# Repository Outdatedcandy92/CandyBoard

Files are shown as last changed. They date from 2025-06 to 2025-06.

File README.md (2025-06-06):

## Candy Board

Candy Board is a 75% compact keyboard powered by a Raspberry Pi Pico. It includes two knobs and a oled screen on board. Along with a 75% Keyboard you have a seperated dedicated numpad.



### Inspiration

I daily drive a keychron K2 and I really love that keyboard but I really wished it had better media control keys and seperate numpad for number crunching. To address these problems I added two rotary encodes on top and a mini oled screen on the main keyboard and also designed a seperate numpad

### BOM

**Prices are in CAD unless specified**
| **Component** | **Quantity Needed** | **Lot Price** | **Unit Price** |
| --- | --- | --- | --- |
| [Raspberry Pi Pico Clones](https://www.aliexpress.com/item/1005003371056277.html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) | 2 | $6.30 | $3.15 |
| **PCB** | - | $44.46 + $34.91 (Shipping) - $14.03 (Coupon) = **$65.34** | - |
| **Keyboard** | 1 | - | $31.84 |
| **Numpad** | 1 | - | $12.62 |
| **3D Case** [1 Kg Filament](https://www.amazon.ca/ELEGOO-Filament-Dimensional-Accuracy-Carboard/dp/B0CFV3WF7P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) | 5 | $25 | - |
| &nbsp;&nbsp;&nbsp;&nbsp;• Keyboard (Top, Bottom, Plate) | 3 | - | - |
| &nbsp;&nbsp;&nbsp;&nbsp;• Numpad (Case, Plate) | 2 | - | - |
| **Acrylic Cutout** | 2 | - | - |
| &nbsp;&nbsp;&nbsp;&nbsp;• Keyboard | 1 | - | - |
| &nbsp;&nbsp;&nbsp;&nbsp;• Numpad | 1 | - | - |
| [EC11 15mm Rotary Encoder](https://www.aliexpress.com/item/1005005721641382.html) | 2 | $5.34 | ~$1.00 |
| [MCP23017](https://www.aliexpress.com/item/1005005363863079.html) | 1 | $4.42 | $4.42 |
| [1N4148](https://www.aliexpress.com/item/1005002339916163.html) | 101 | $1.27 | $0.13 |
| [Cherry MX Red](https://www.aliexpress.com/item/1005006255961111.html) | 101 | $39.22 | $0.35 |
| [Keycaps](https://www.aliexpress.com/item/1005007393936770.html) | 1 set | $31.18 | $31.18 |
| [Stabilizer Set](https://www.aliexpress.com/item/1005001686319745.html) | 1 set | $8.67 | $8.67 |
| [SSD1306 0.91'' OLED](https://www.aliexpress.com/item/1005007302239124.html) | 1 | $4.42 | $4.42 |
| [SK6812 Mini-E](https://www.aliexpress.com/item/1005005193716172.html) | 8 | $3.18 | $0.16 |
| [Rubber Feet](https://www.aliexpress.com/item/1005006211282720.html) | 2 sets | $8.02 | $4.01 |
| [EVA Foam](https://www.aliexpress.com/item/1005002856054113.html) | 1 | $6.79 | $6.79 |
| **Sub Total** | - | **~$210** | - |
| **Taxes (13%)** | - | **~$27** | - |
| **Grand Total** | - | **~$237** = $174 USD | - |

### CAD Model:

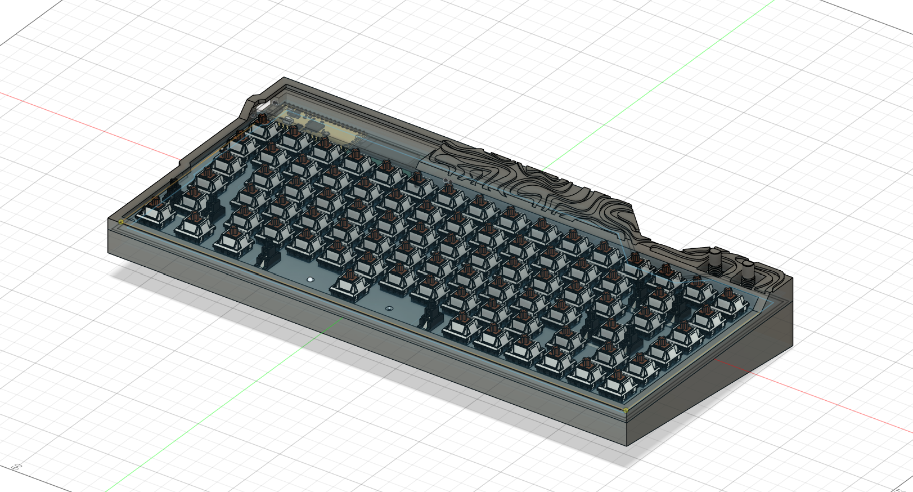
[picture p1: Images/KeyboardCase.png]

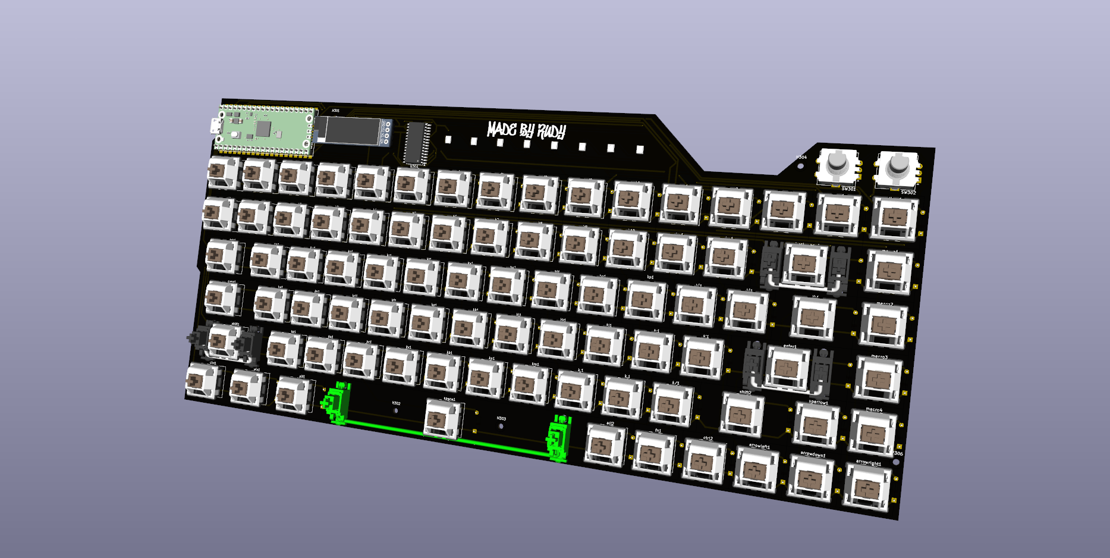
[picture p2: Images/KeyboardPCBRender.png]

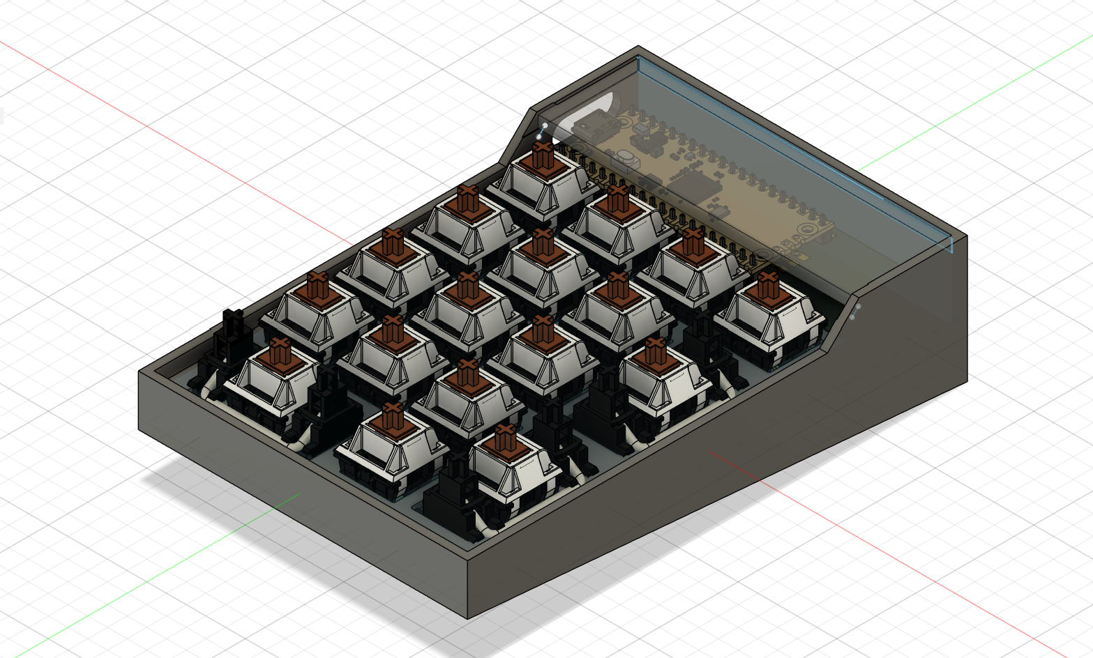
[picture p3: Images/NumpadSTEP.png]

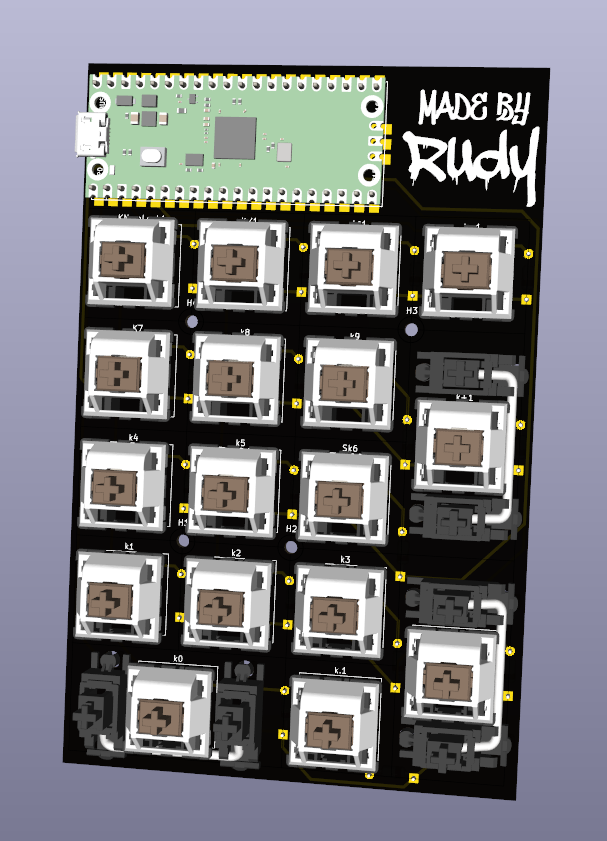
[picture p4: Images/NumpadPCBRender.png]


### PCB & Schematic
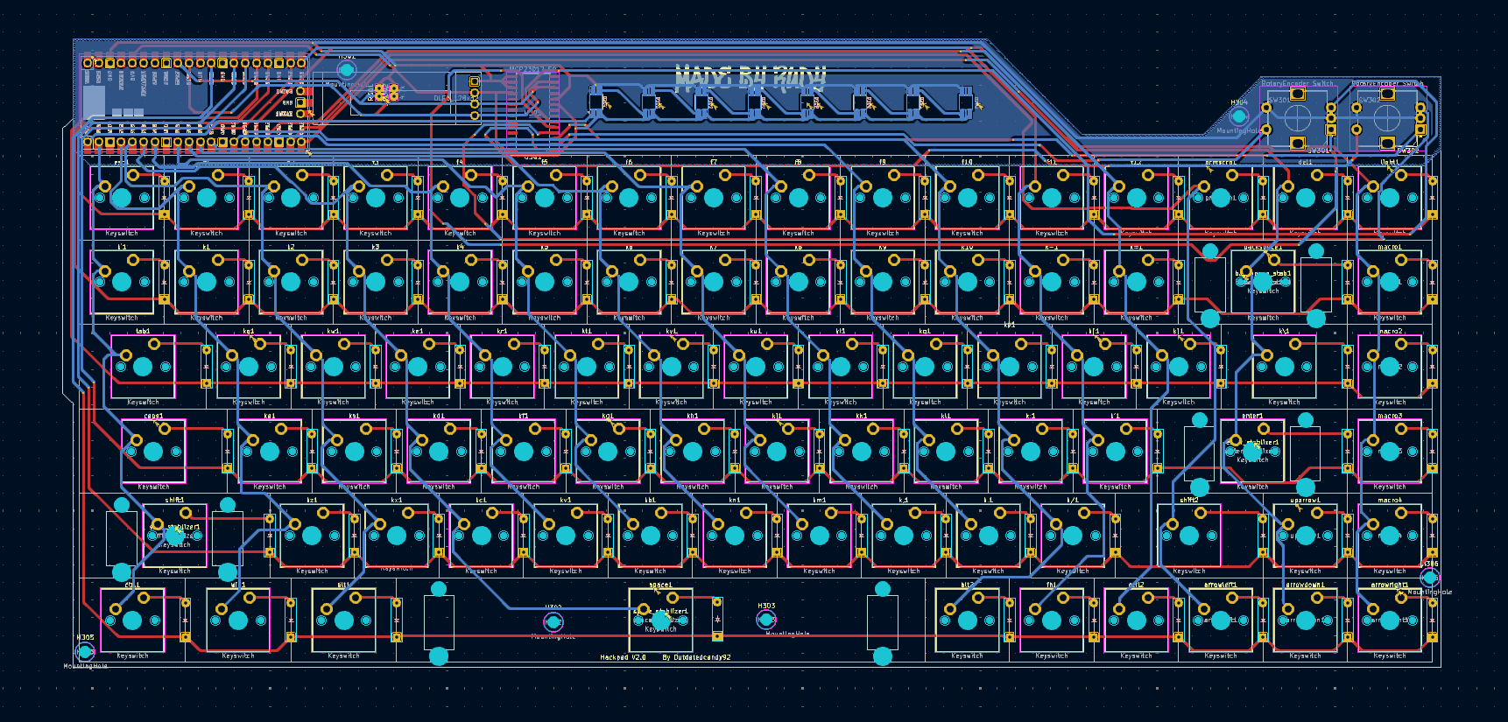
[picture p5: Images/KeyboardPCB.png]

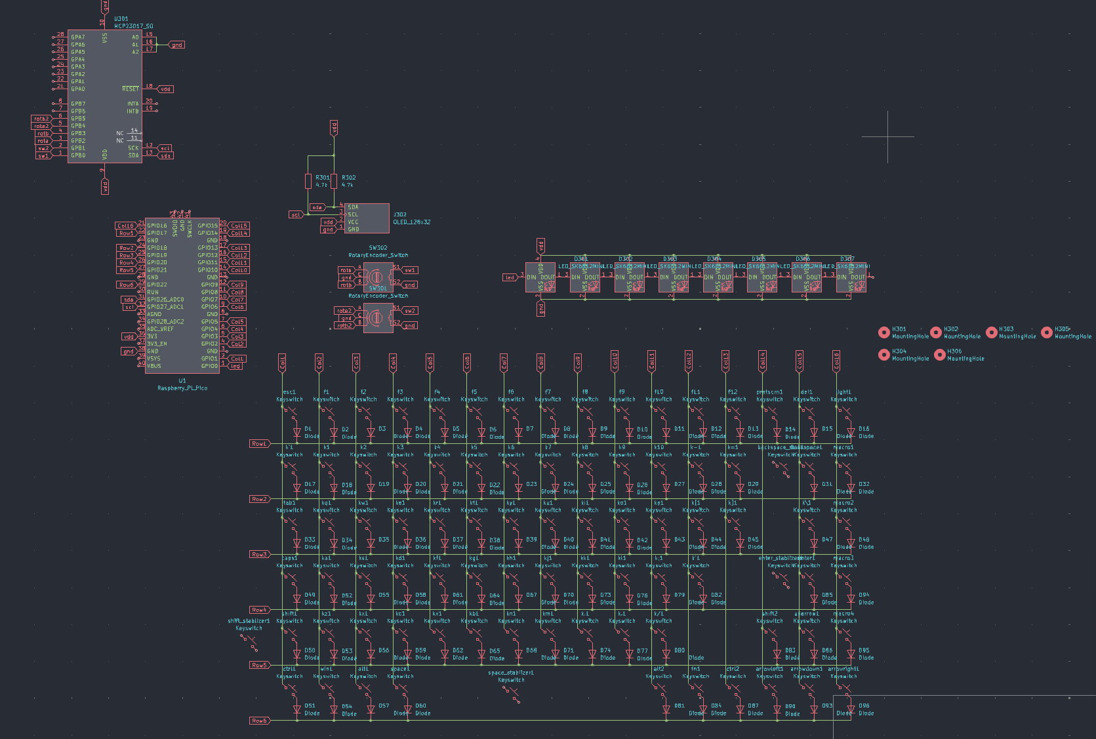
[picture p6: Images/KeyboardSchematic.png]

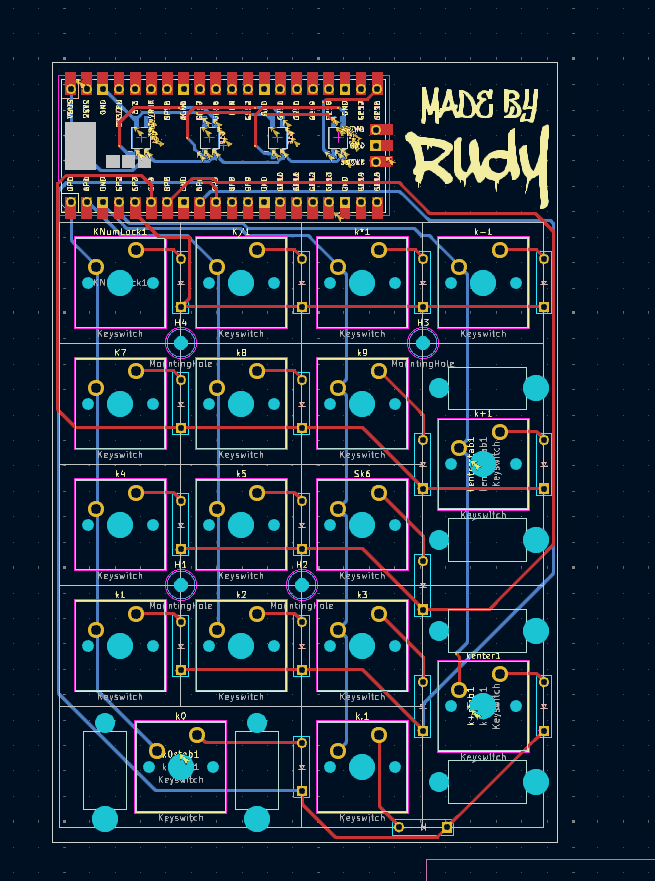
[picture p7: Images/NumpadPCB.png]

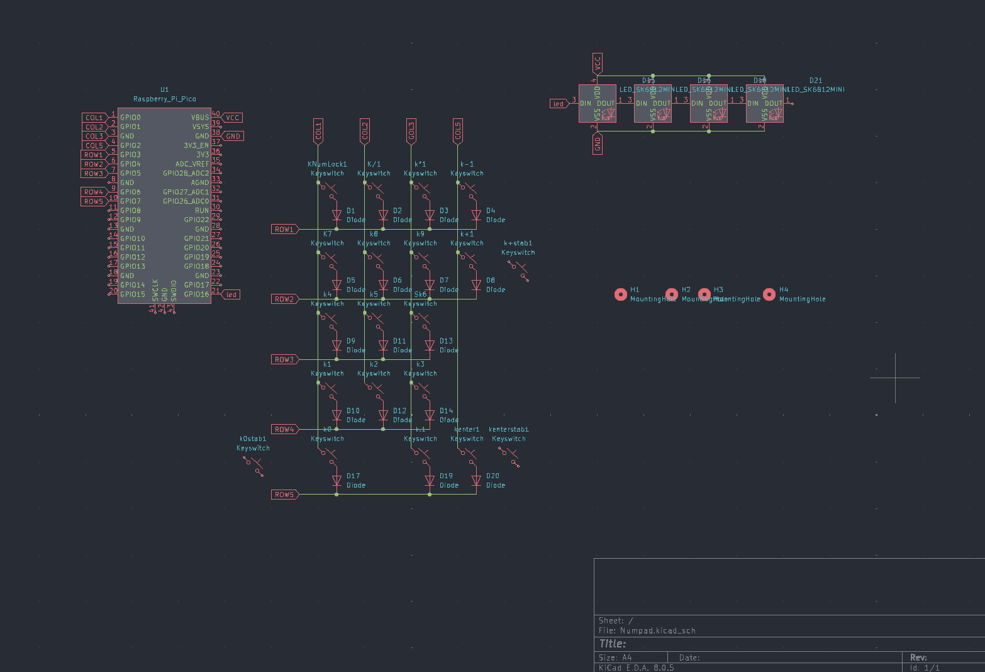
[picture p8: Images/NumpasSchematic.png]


### Firmware

Firmware was written using kmk. (no idea if it work rn tho)

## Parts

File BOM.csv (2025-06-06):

Item | Quantity Needed | Lot Price | Unit Price
Raspberry Pi Pico Clones | 2 | $6.30 | $3.15
PCB | - | $44.46 + $34.91 (Shipping) - $14.03 (Coupon) = $65.34 | -
Keyboard | 1 | - | $31.84
Numpad | 1 | - | $12.62
3D Case (1 Kg Filament) | 5 | $25 | -
• Keyboard (Top | Bottom | Plate) | 3 | - | -
• Numpad (Case | Plate) | 2 | - | -
Acrylic Cutout | 2 | - | -
• Keyboard | 1 | - | -
• Numpad | 1 | - | -
EC11 15mm Rotary Encoder | 2 | $5.34 | ~$1.00
MCP23017 | 1 | $4.42 | $4.42
1N4148 | 101 | $1.27 | $0.13
Cherry MX Red | 101 | $39.22 | $0.35
Keycaps (1 set) | 1 | $31.18 | $31.18
Stabilizer Set (1 set) | 1 | $8.67 | $8.67
SSD1306 0.91'' OLED | 1 | $4.42 | $4.42
SK6812 Mini-E | 8 | $3.18 | $0.16
Rubber Feet (2 sets) | 2 | $8.02 | $4.01
EVA Foam | 1 | $6.79 | $6.79
Sub Total | - | $210 | -
Taxes (13%) | - | $27 | -
Grand Total | - | $237 CAD ≈ $174 USD | -

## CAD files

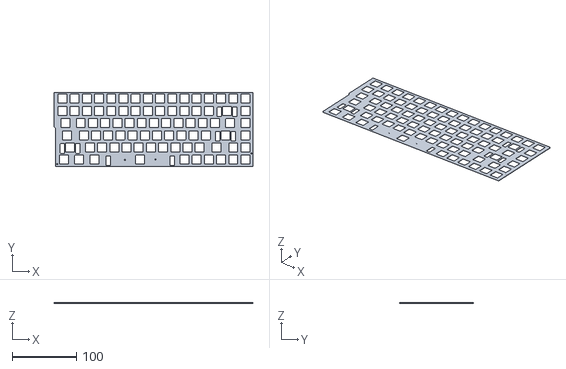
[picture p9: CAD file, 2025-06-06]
Production/Keyboard/KeyboardPlate.stl
310.8 x 115.3 x 1.50

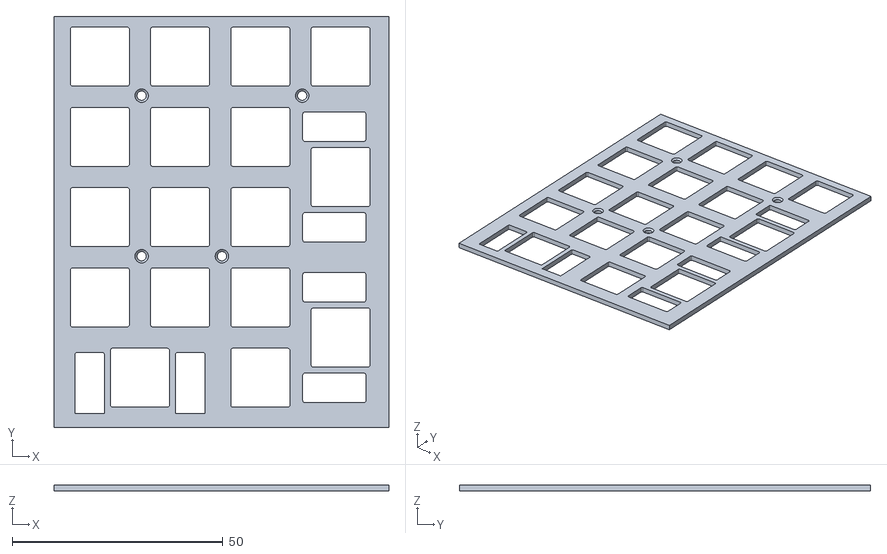
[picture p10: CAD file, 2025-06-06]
Production/Numpad/NumpadPlate.stl
79.5 x 97.6 x 1.50

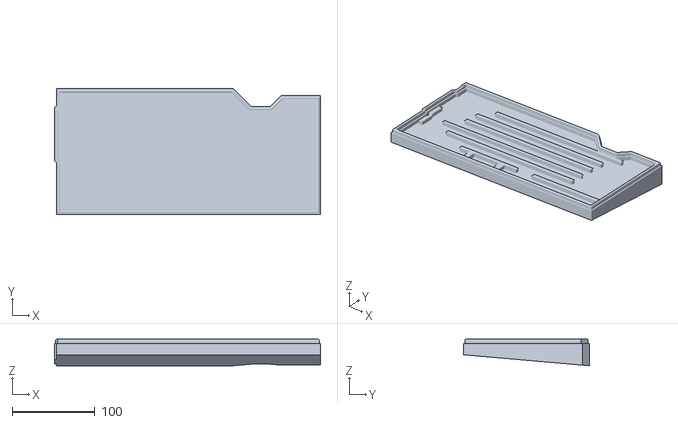
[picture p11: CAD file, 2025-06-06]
Production/Keyboard/KeyboardBottomCase.stl
320.8 x 151.7 x 32.0

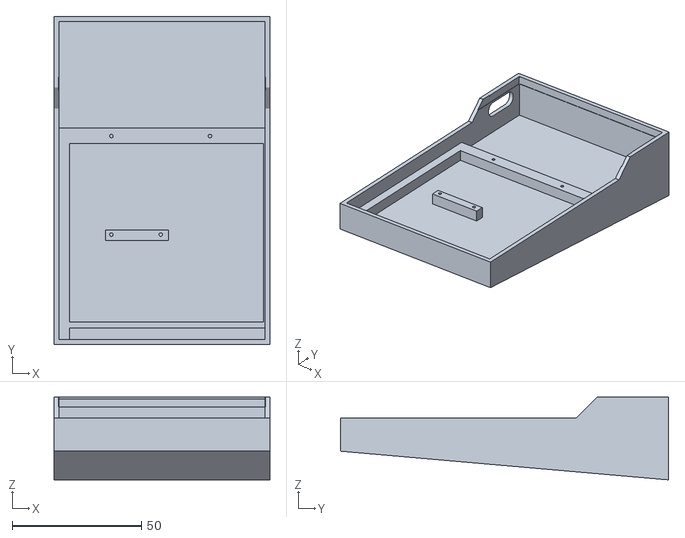
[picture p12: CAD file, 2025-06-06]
Production/Numpad/NumpadCase.stl
83.5 x 126.8 x 32.0

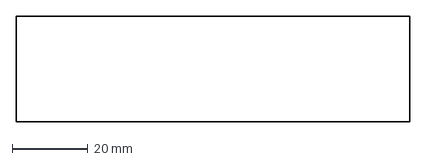
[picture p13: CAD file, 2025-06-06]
Production/Keyboard/KeyboardAcrylic.dxf
104.0 x 28.0 mm

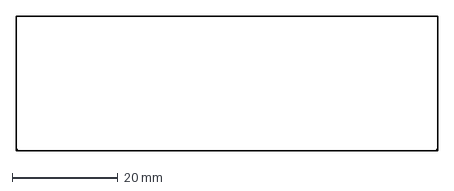
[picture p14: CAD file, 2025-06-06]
Production/Numpad/NumpadAcryllic.dxf
79.9 x 25.4 mm

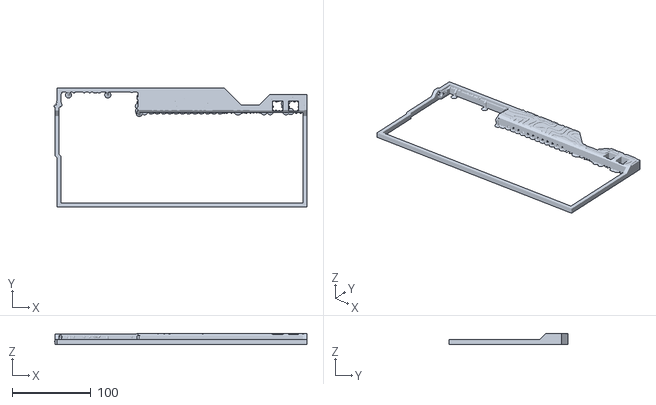
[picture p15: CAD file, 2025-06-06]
Production/Keyboard/KeyboardTopCaseWsupport.stl
322.3 x 151.7 x 14.6

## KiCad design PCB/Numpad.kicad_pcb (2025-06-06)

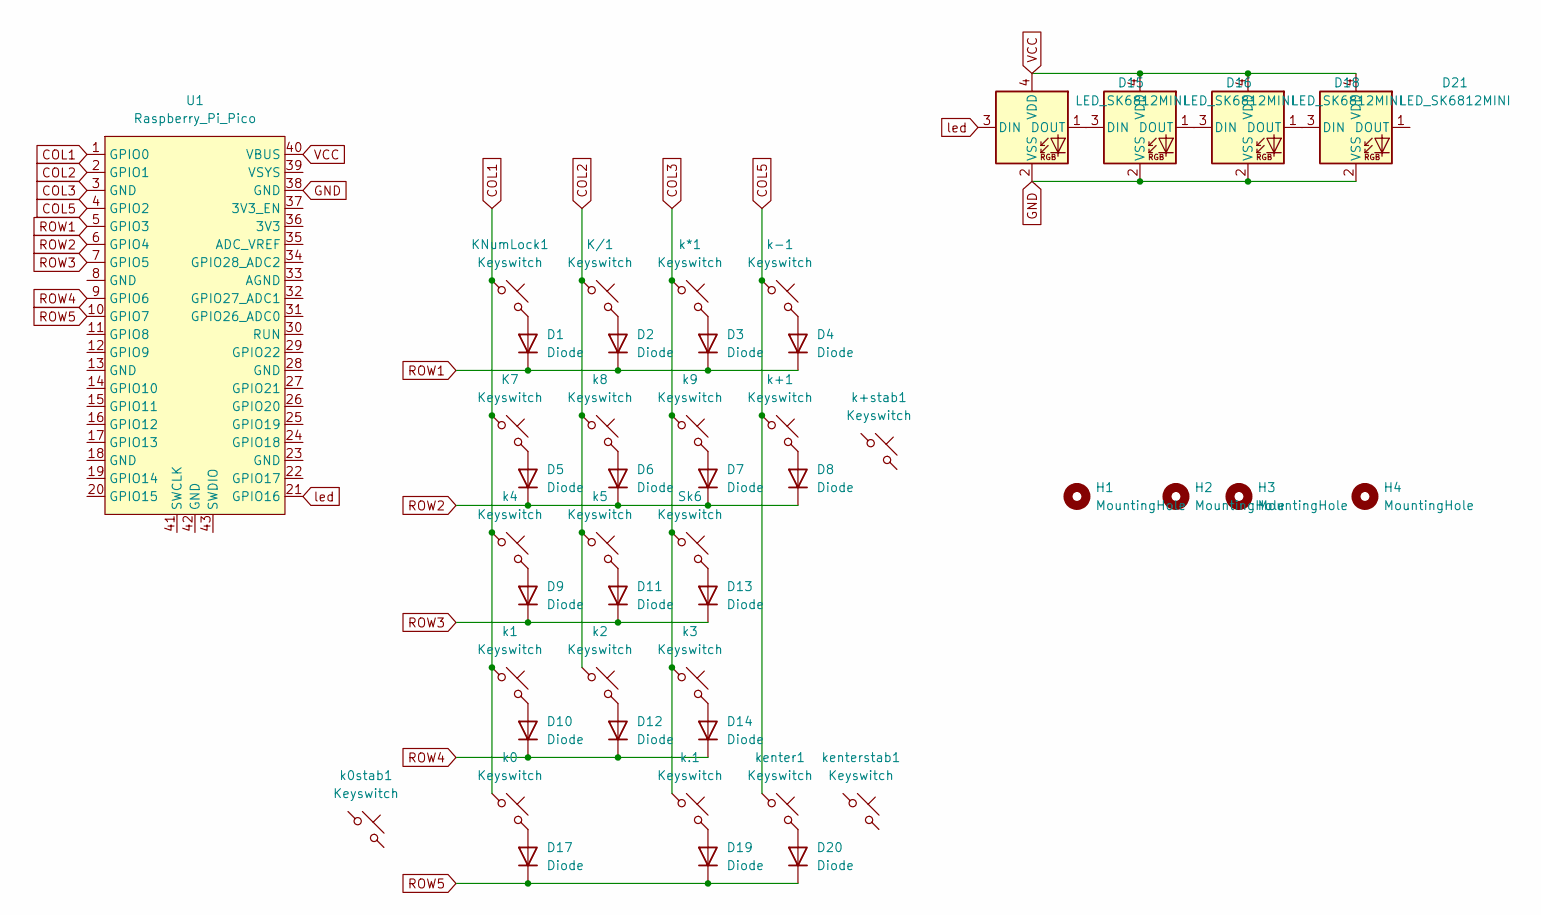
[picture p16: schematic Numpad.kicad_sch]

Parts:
D1, D2, D3, D4, D5, D6, D7, D8, D9, D10, D11, D12, D13, D14, D17, D19, D20: Diode; Diode_DO-35
D15, D16, D18, D21: LED_SK6812MINI
H1, H2, H3, H4: MountingHole; MountingHole_2.2mm_M2
K7: Keyswitch; MX_PCB_1.00u
K/1: Keyswitch; MX_PCB_1.00u
KNumLock1: Keyswitch; MX_PCB_1.00u
Sk6: Keyswitch; MX_PCB_1.00u
U1: Raspberry_Pi_Pico
k0: Keyswitch; MX_PCB_2.00u
k0stab1: Keyswitch; Stabilizer_MX_2.00u
k1, k2, k3, k4, k5, k8, k9, k.1: Keyswitch; MX_PCB_1.00u
k*1: Keyswitch; MX_PCB_1.00u
k+1: Keyswitch; MX_PCB_2.00u_90deg
k+stab1: Keyswitch; Stabilizer_MX_2.00u
k-1: Keyswitch; MX_PCB_1.00u
kenter1: Keyswitch; MX_PCB_2.00u_90deg
kenterstab1: Keyswitch; Stabilizer_MX_2.00u

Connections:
COL1: K7.1, KNumLock1.1, U1.1 (GPIO0), k0.1, k1.1, k4.1
COL2: K/1.1, U1.2 (GPIO1), k2.1, k5.1, k8.1
COL3: Sk6.1, U1.3 (GND), k3.1, k9.1, k*1.1, k.1.1
COL5: U1.4 (GPIO2), k+1.1, k-1.1, kenter1.1
GND: D15.2 (VSS), D16.2 (VSS), D18.2 (VSS), D21.2 (VSS), U1.38 (GND)
unnamed: D1.2 (A), KNumLock1.2
unnamed: D2.2 (A), K/1.2
unnamed: D3.2 (A), k*1.2
unnamed: D4.2 (A), k-1.2
unnamed: D5.2 (A), K7.2
unnamed: D6.2 (A), k8.2
unnamed: D7.2 (A), k9.2
unnamed: D8.2 (A), k+1.2
unnamed: D9.2 (A), k4.2
unnamed: D10.2 (A), k1.2
unnamed: D11.2 (A), k5.2
unnamed: D12.2 (A), k2.2
unnamed: D13.2 (A), Sk6.2
unnamed: D14.2 (A), k3.2
unnamed: D15.1 (DOUT), D16.3 (DIN)
unnamed: D16.1 (DOUT), D18.3 (DIN)
unnamed: D17.2 (A), k0.2
unnamed: D18.1 (DOUT), D21.3 (DIN)
unnamed: D19.2 (A), k.1.2
unnamed: D20.2 (A), kenter1.2
ROW1: D1.1 (K), D2.1 (K), D3.1 (K), D4.1 (K), U1.5 (GPIO3)
ROW2: D5.1 (K), D6.1 (K), D7.1 (K), D8.1 (K), U1.6 (GPIO4)
ROW3: D9.1 (K), D11.1 (K), D13.1 (K), U1.7 (GPIO5)
ROW4: D10.1 (K), D12.1 (K), D14.1 (K), U1.9 (GPIO6)
ROW5: D17.1 (K), D19.1 (K), D20.1 (K), U1.10 (GPIO7)
VCC: D15.4 (VDD), D16.4 (VDD), D18.4 (VDD), D21.4 (VDD), U1.40 (VBUS)
led: D15.3 (DIN), U1.21 (GPIO16)

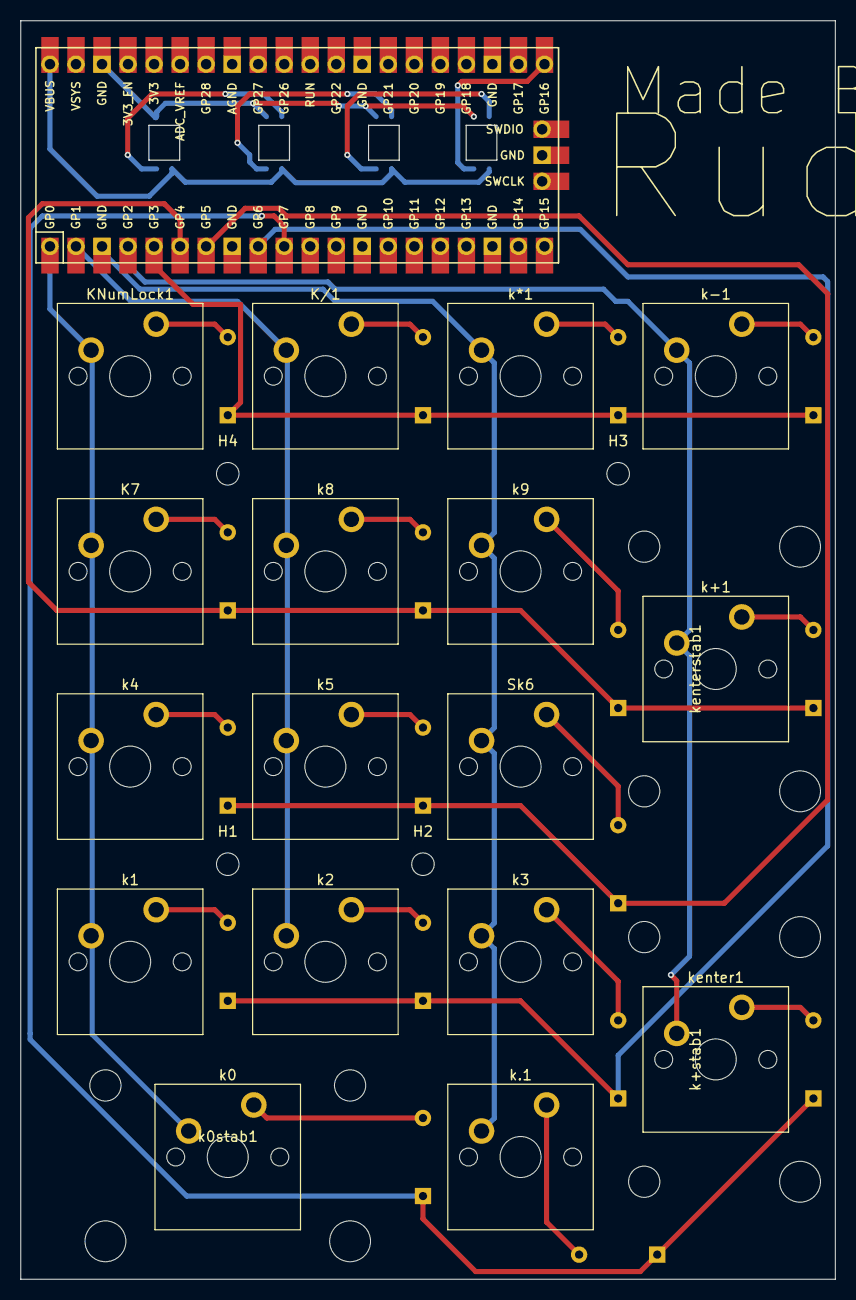
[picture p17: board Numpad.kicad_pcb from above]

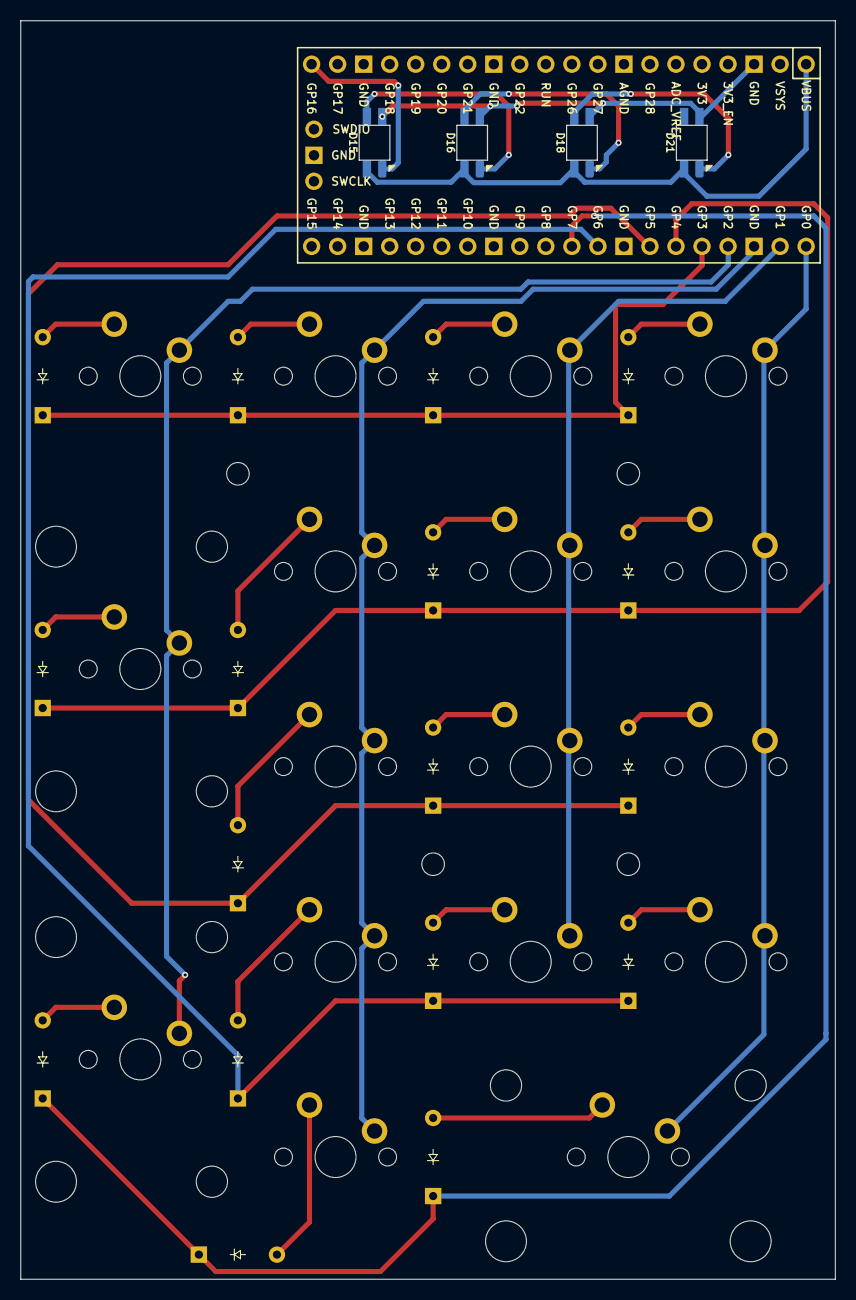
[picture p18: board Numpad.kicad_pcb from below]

Board: 2 copper layers, 79.5 x 122.8 mm, 46 parts (17 on the bottom side), 32 nets.

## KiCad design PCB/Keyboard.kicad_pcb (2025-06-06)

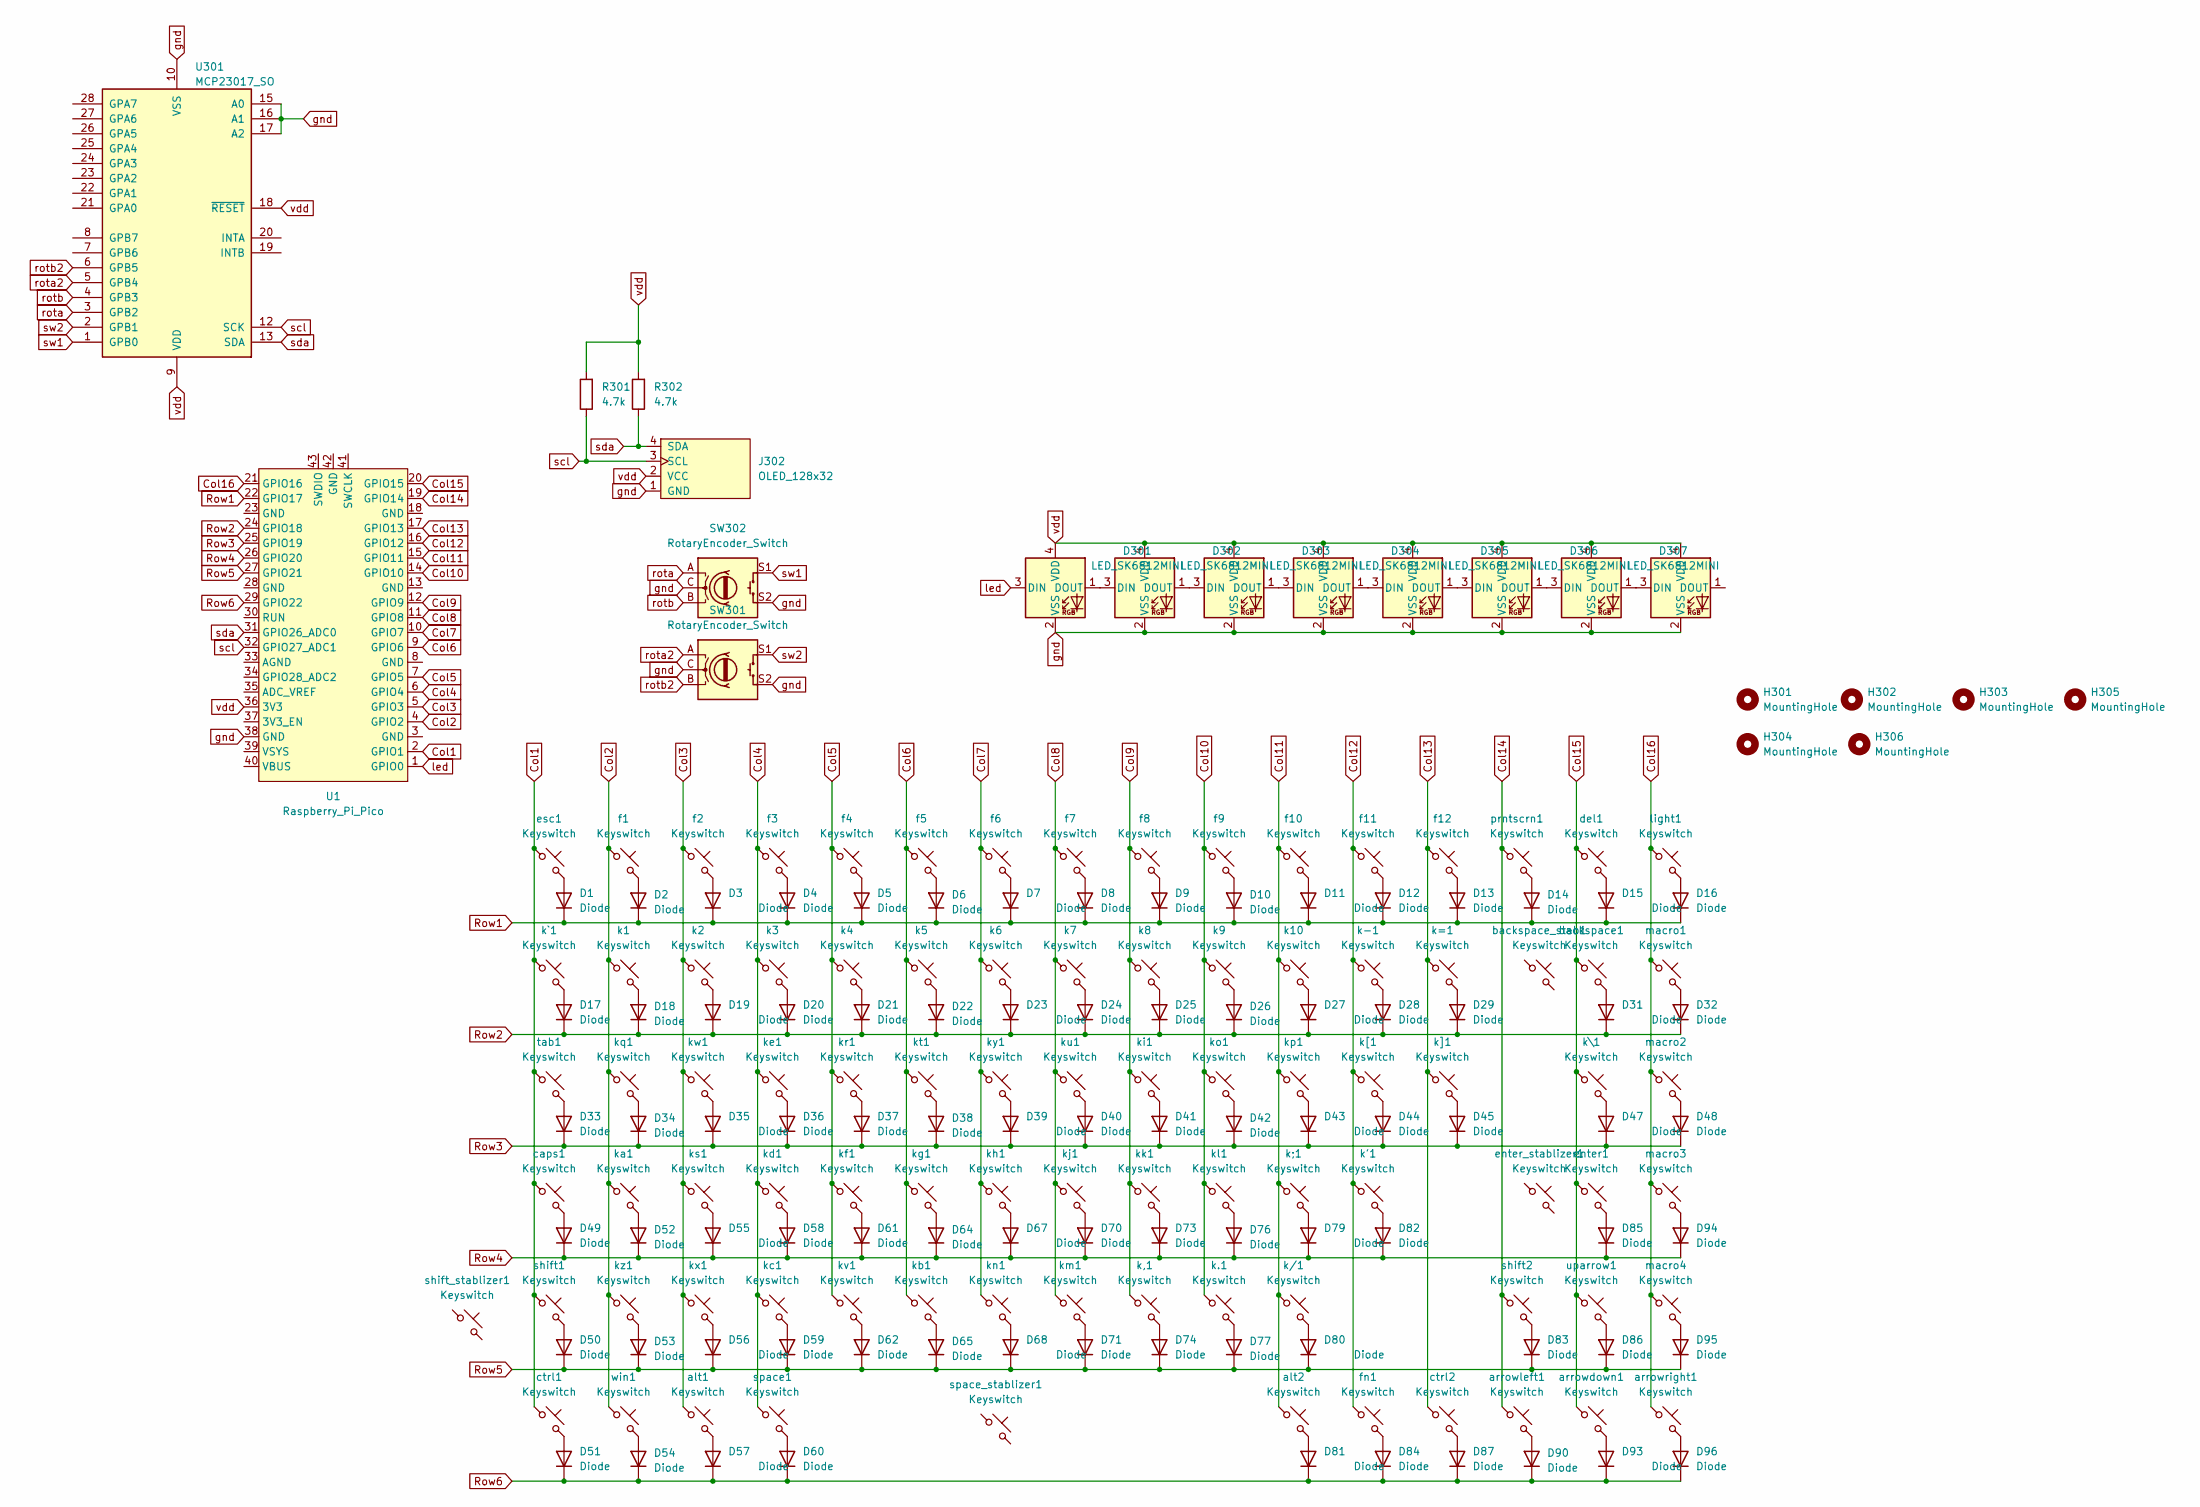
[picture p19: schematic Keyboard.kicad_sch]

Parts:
D1, D2, D3, D4, D5, D6, D7, D8, D9, D10, D11, D12, D13, D14, D15, D16, D17, D18, D19, D20, D21, D22, D23, D24, D25, D26, D27, D28, D29, D31, D32, D33, D34, D35, D36, D37, D38, D39, D40, D41, D42, D43, D44, D45, D47, D48, D49, D50, D51, D52, D53, D54, D55, D56, D57, D58, D59, D60, D61, D62, D64, D65, D67, D68, D70, D71, D73, D74, D76, D77, D79, D80, D81, D82, D83, D84, D85, D86, D87, D90, D93, D94, D95, D96: Diode; Diode_DO-35
D301, D302, D303, D304, D305, D306, D307, D308: LED_SK6812MINI
H301, H302, H303, H304, H305, H306: MountingHole; MountingHole_2.2mm_M2
J302: OLED_128x32
R301, R302: 4.7k; R_Axial_DIN0204_L3.6mm_D1.6mm_P1.90mm_Vertical
SW301, SW302: RotaryEncoder_Switch; RotaryEncoder_Alps_EC12E-Switch_Vertical_H20mm
U1: Raspberry_Pi_Pico
U301: MCP23017_SO; SOIC-28W_7.5x17.9mm_P1.27mm
alt1: Keyswitch; MX_PCB_1.25u
alt2: Keyswitch; MX_PCB_1.00u
arrowdown1: Keyswitch; MX_PCB_1.00u
arrowleft1: Keyswitch; MX_PCB_1.00u
arrowright1: Keyswitch; MX_PCB_1.00u
backspace1: Keyswitch; MX_PCB_2.00u
backspace_stab1: Keyswitch; Stabilizer_MX_2.00u
caps1: Keyswitch; MX_PCB_1.75u
ctrl1: Keyswitch; MX_PCB_1.25u
ctrl2: Keyswitch; MX_PCB_1.00u
del1: Keyswitch; MX_PCB_1.00u
enter1: Keyswitch; MX_PCB_2.25u
enter_stablizer1: Keyswitch; Stabilizer_MX_2.00u
esc1: Keyswitch; MX_PCB_1.00u
f1, f2, f3, f4, f5, f6, f7, f8, f9, f10, f11, f12: Keyswitch; MX_PCB_1.00u
fn1: Keyswitch; MX_PCB_1.00u
k1, k2, k3, k4, k5, k6, k7, k8, k9, k10, k.1: Keyswitch; MX_PCB_1.00u
k'1: Keyswitch; MX_PCB_1.00u
k,1: Keyswitch; MX_PCB_1.00u
k-1: Keyswitch; MX_PCB_1.00u
k/1: Keyswitch; MX_PCB_1.00u
k;1: Keyswitch; MX_PCB_1.00u
k=1: Keyswitch; MX_PCB_1.00u
k[1: Keyswitch; MX_PCB_1.00u
k\1: Keyswitch; MX_PCB_1.50u
k]1: Keyswitch; MX_PCB_1.00u
k`1: Keyswitch; MX_PCB_1.00u
ka1: Keyswitch; MX_PCB_1.00u
kb1: Keyswitch; MX_PCB_1.00u
kc1: Keyswitch; MX_PCB_1.00u
kd1: Keyswitch; MX_PCB_1.00u
ke1: Keyswitch; MX_PCB_1.00u
kf1: Keyswitch; MX_PCB_1.00u
kg1: Keyswitch; MX_PCB_1.00u
kh1: Keyswitch; MX_PCB_1.00u
ki1: Keyswitch; MX_PCB_1.00u
kj1: Keyswitch; MX_PCB_1.00u
kk1: Keyswitch; MX_PCB_1.00u
kl1: Keyswitch; MX_PCB_1.00u
km1: Keyswitch; MX_PCB_1.00u
kn1: Keyswitch; MX_PCB_1.00u
ko1: Keyswitch; MX_PCB_1.00u
kp1: Keyswitch; MX_PCB_1.00u
kq1: Keyswitch; MX_PCB_1.00u
kr1: Keyswitch; MX_PCB_1.00u
ks1: Keyswitch; MX_PCB_1.00u
kt1: Keyswitch; MX_PCB_1.00u
ku1: Keyswitch; MX_PCB_1.00u
kv1: Keyswitch; MX_PCB_1.00u
kw1: Keyswitch; MX_PCB_1.00u
kx1: Keyswitch; MX_PCB_1.00u
ky1: Keyswitch; MX_PCB_1.00u
kz1: Keyswitch; MX_PCB_1.00u
light1: Keyswitch; MX_PCB_1.00u
macro1, macro2, macro3, macro4: Keyswitch; MX_PCB_1.00u
prntscrn1: Keyswitch; MX_PCB_1.00u
shift1: Keyswitch; MX_PCB_2.25u
shift2: Keyswitch; MX_PCB_1.75u
shift_stablizer1: Keyswitch; Stabilizer_MX_2.00u
space1: Keyswitch; MX_PCB_6.25u
space_stablizer1: Keyswitch; Stabilizer_MX_6.25u
tab1: Keyswitch; MX_PCB_1.50u
uparrow1: Keyswitch; MX_PCB_1.00u
win1: Keyswitch; MX_PCB_1.25u

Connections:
Col1: U1.2 (GPIO1), caps1.1, ctrl1.1, esc1.1, k`1.1, shift1.1, tab1.1
Col2: U1.4 (GPIO2), f1.1, k1.1, ka1.1, kq1.1, kz1.1, win1.1
Col3: U1.5 (GPIO3), alt1.1, f2.1, k2.1, ks1.1, kw1.1, kx1.1
Col4: U1.6 (GPIO4), f3.1, k3.1, kc1.1, kd1.1, ke1.1, space1.1
Col5: U1.7 (GPIO5), f4.1, k4.1, kf1.1, kr1.1, kv1.1
Col6: U1.9 (GPIO6), f5.1, k5.1, kb1.1, kg1.1, kt1.1
Col7: U1.10 (GPIO7), f6.1, k6.1, kh1.1, kn1.1, ky1.1
Col8: U1.11 (GPIO8), f7.1, k7.1, kj1.1, km1.1, ku1.1
Col9: U1.12 (GPIO9), f8.1, k8.1, k,1.1, ki1.1, kk1.1
Col10: U1.14 (GPIO10), f9.1, k9.1, k.1.1, kl1.1, ko1.1
Col11: U1.15 (GPIO11), alt2.1, f10.1, k10.1, k/1.1, k;1.1, kp1.1
Col12: U1.16 (GPIO12), f11.1, fn1.1, k'1.1, k-1.1, k[1.1
Col13: U1.17 (GPIO13), ctrl2.1, f12.1, k=1.1, k]1.1
Col14: U1.19 (GPIO14), arrowleft1.1, prntscrn1.1, shift2.1
Col15: U1.20 (GPIO15), arrowdown1.1, backspace1.1, del1.1, enter1.1, k\1.1, uparrow1.1
Col16: U1.21 (GPIO16), arrowright1.1, light1.1, macro1.1, macro2.1, macro3.1, macro4.1
unnamed: D1.2 (A), esc1.2
unnamed: D2.2 (A), f1.2
unnamed: D3.2 (A), f2.2
unnamed: D4.2 (A), f3.2
unnamed: D5.2 (A), f4.2
unnamed: D6.2 (A), f5.2
unnamed: D7.2 (A), f6.2
unnamed: D8.2 (A), f7.2
unnamed: D9.2 (A), f8.2
unnamed: D10.2 (A), f9.2
unnamed: D11.2 (A), f10.2
unnamed: D12.2 (A), f11.2
unnamed: D13.2 (A), f12.2
unnamed: D14.2 (A), prntscrn1.2
unnamed: D15.2 (A), del1.2
unnamed: D16.2 (A), light1.2
unnamed: D17.2 (A), k`1.2
unnamed: D18.2 (A), k1.2
unnamed: D19.2 (A), k2.2
unnamed: D20.2 (A), k3.2
unnamed: D21.2 (A), k4.2
unnamed: D22.2 (A), k5.2
unnamed: D23.2 (A), k6.2
unnamed: D24.2 (A), k7.2
unnamed: D25.2 (A), k8.2
unnamed: D26.2 (A), k9.2
unnamed: D27.2 (A), k10.2
unnamed: D28.2 (A), k-1.2
unnamed: D29.2 (A), k=1.2
unnamed: D31.2 (A), backspace1.2
unnamed: D32.2 (A), macro1.2
unnamed: D33.2 (A), tab1.2
unnamed: D34.2 (A), kq1.2
unnamed: D35.2 (A), kw1.2
unnamed: D36.2 (A), ke1.2
unnamed: D37.2 (A), kr1.2
unnamed: D38.2 (A), kt1.2
unnamed: D39.2 (A), ky1.2
unnamed: D40.2 (A), ku1.2
unnamed: D41.2 (A), ki1.2
unnamed: D42.2 (A), ko1.2
unnamed: D43.2 (A), kp1.2
unnamed: D44.2 (A), k[1.2
unnamed: D45.2 (A), k]1.2
unnamed: D47.2 (A), k\1.2
unnamed: D48.2 (A), macro2.2
unnamed: D49.2 (A), caps1.2
unnamed: D50.2 (A), shift1.2
unnamed: D51.2 (A), ctrl1.2
unnamed: D52.2 (A), ka1.2
unnamed: D53.2 (A), kz1.2
unnamed: D54.2 (A), win1.2
unnamed: D55.2 (A), ks1.2
unnamed: D56.2 (A), kx1.2
unnamed: D57.2 (A), alt1.2
unnamed: D58.2 (A), kd1.2
unnamed: D59.2 (A), kc1.2
unnamed: D60.2 (A), space1.2
unnamed: D61.2 (A), kf1.2
unnamed: D62.2 (A), kv1.2
unnamed: D64.2 (A), kg1.2
unnamed: D65.2 (A), kb1.2
unnamed: D67.2 (A), kh1.2
unnamed: D68.2 (A), kn1.2
unnamed: D70.2 (A), kj1.2
unnamed: D71.2 (A), km1.2
unnamed: D73.2 (A), kk1.2
unnamed: D74.2 (A), k,1.2
unnamed: D76.2 (A), kl1.2
unnamed: D77.2 (A), k.1.2
unnamed: D79.2 (A), k;1.2
unnamed: D80.2 (A), k/1.2
unnamed: D81.2 (A), alt2.2
unnamed: D82.2 (A), k'1.2
unnamed: D83.2 (A), shift2.2
unnamed: D84.2 (A), fn1.2
unnamed: D85.2 (A), enter1.2
unnamed: D86.2 (A), uparrow1.2
unnamed: D87.2 (A), ctrl2.2
unnamed: D90.2 (A), arrowleft1.2
unnamed: D93.2 (A), arrowdown1.2
unnamed: D94.2 (A), macro3.2
unnamed: D95.2 (A), macro4.2
unnamed: D96.2 (A), arrowright1.2
unnamed: D301.1 (DOUT), D302.3 (DIN)
unnamed: D302.1 (DOUT), D303.3 (DIN)
unnamed: D303.1 (DOUT), D304.3 (DIN)
unnamed: D304.1 (DOUT), D305.3 (DIN)
unnamed: D305.1 (DOUT), D306.3 (DIN)
unnamed: D306.1 (DOUT), D307.3 (DIN)
unnamed: D307.1 (DOUT), D308.3 (DIN)
Row1: D1.1 (K), D2.1 (K), D3.1 (K), D4.1 (K), D5.1 (K), D6.1 (K), D7.1 (K), D8.1 (K), D9.1 (K), D10.1 (K), D11.1 (K), D12.1 (K), D13.1 (K), D14.1 (K), D15.1 (K), D16.1 (K), U1.22 (GPIO17)
Row2: D17.1 (K), D18.1 (K), D19.1 (K), D20.1 (K), D21.1 (K), D22.1 (K), D23.1 (K), D24.1 (K), D25.1 (K), D26.1 (K), D27.1 (K), D28.1 (K), D29.1 (K), D31.1 (K), D32.1 (K), U1.24 (GPIO18)
Row3: D33.1 (K), D34.1 (K), D35.1 (K), D36.1 (K), D37.1 (K), D38.1 (K), D39.1 (K), D40.1 (K), D41.1 (K), D42.1 (K), D43.1 (K), D44.1 (K), D45.1 (K), D47.1 (K), D48.1 (K), U1.25 (GPIO19)
Row4: D49.1 (K), D52.1 (K), D55.1 (K), D58.1 (K), D61.1 (K), D64.1 (K), D67.1 (K), D70.1 (K), D73.1 (K), D76.1 (K), D79.1 (K), D82.1 (K), D85.1 (K), D94.1 (K), U1.26 (GPIO20)
Row5: D50.1 (K), D53.1 (K), D56.1 (K), D59.1 (K), D62.1 (K), D65.1 (K), D68.1 (K), D71.1 (K), D74.1 (K), D77.1 (K), D80.1 (K), D83.1 (K), D86.1 (K), D95.1 (K), U1.27 (GPIO21)
Row6: D51.1 (K), D54.1 (K), D57.1 (K), D60.1 (K), D81.1 (K), D84.1 (K), D87.1 (K), D90.1 (K), D93.1 (K), D96.1 (K), U1.29 (GPIO22)
gnd: D301.2 (VSS), D302.2 (VSS), D303.2 (VSS), D304.2 (VSS), D305.2 (VSS), D306.2 (VSS), D307.2 (VSS), D308.2 (VSS), J302.1 (GND), SW301.C, SW301.S2, SW302.C, SW302.S2, U1.38 (GND), U301.10 (VSS), U301.15 (A0), U301.16 (A1), U301.17 (A2)
led: D301.3 (DIN), U1.1 (GPIO0)
rota: SW302.A, U301.3 (GPB2)
rota2: SW301.A, U301.5 (GPB4)
rotb: SW302.B, U301.4 (GPB3)
rotb2: SW301.B, U301.6 (GPB5)
scl: J302.3 (SCL), R301.1, U1.32 (GPIO27_ADC1), U301.12 (SCK)
sda: J302.4 (SDA), R302.1, U1.31 (GPIO26_ADC0), U301.13 (SDA)
sw1: SW302.S1, U301.1 (GPB0)
sw2: SW301.S1, U301.2 (GPB1)
vdd: D301.4 (VDD), D302.4 (VDD), D303.4 (VDD), D304.4 (VDD), D305.4 (VDD), D306.4 (VDD), D307.4 (VDD), D308.4 (VDD), J302.2 (VCC), R301.2, R302.2, U1.36 (3V3), U301.9 (VDD), U301.18 (~RESET)

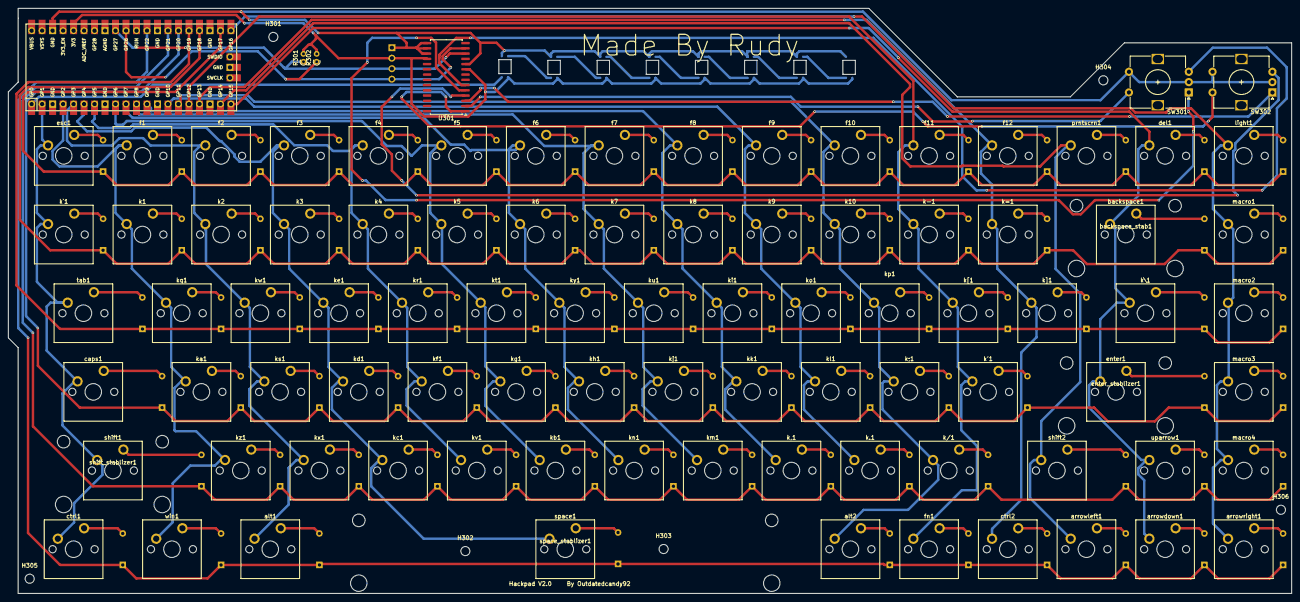
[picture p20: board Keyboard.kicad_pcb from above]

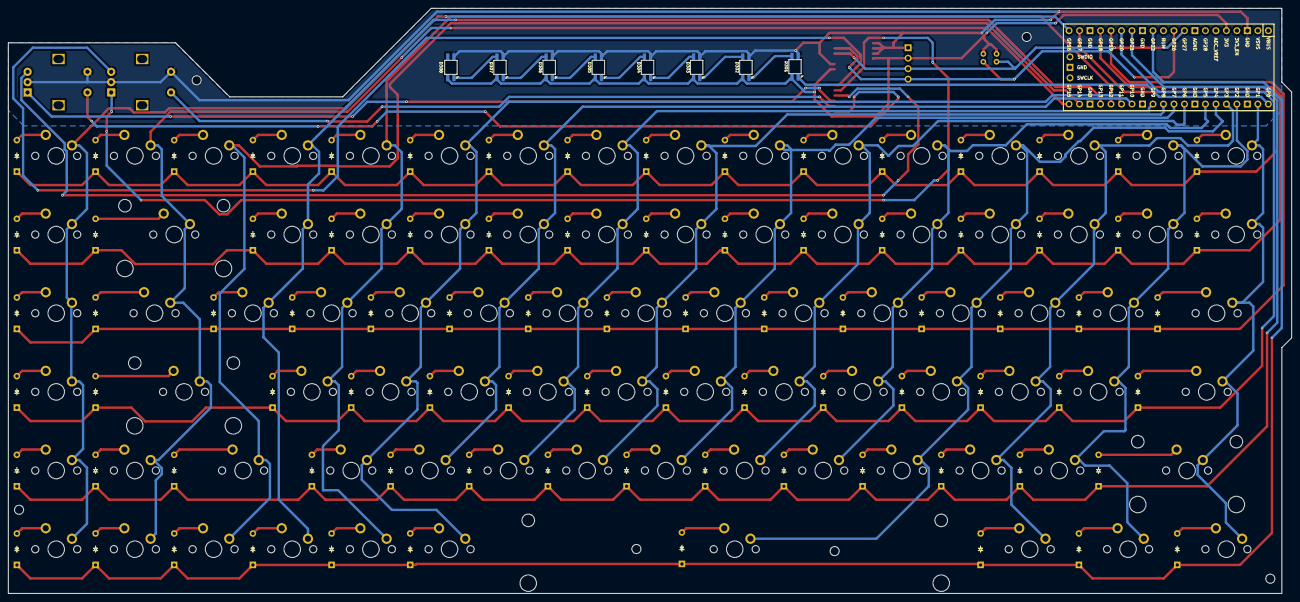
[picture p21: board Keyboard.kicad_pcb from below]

Board: 2 copper layers, 310.8 x 141.7 mm, 193 parts (84 on the bottom side), 124 nets.

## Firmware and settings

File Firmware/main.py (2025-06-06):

from kmk.kmk_keyboard import KMKKeyboard
from kmk.scanners.keypad import MatrixScanner
from kmk.modules.encoder import EncoderHandler
from kmk.modules.split import SplitKeyboard
from kmk.extensions.led import RGB
import board
import busio
from kmk.modules.mcp23017 import MCP23017
import digitalio
import neopixel
import time
import math

keyboard = KMKKeyboard()

# GPIO Setup for the Key Matrix
keyboard.matrix = MatrixScanner(
    cols=[board.GP1, board.GP2, board.GP3, board.GP4, board.GP5, board.GP6, board.GP7,
          board.GP8, board.GP9, board.GP10, board.GP11, board.GP12, board.GP13, board.GP14, board.GP15, board.GP16],
    rows=[board.GP17, board.GP18, board.GP19, board.GP20, board.GP21, board.GP22],
    diodes='COL2ROW',  # Updated to include diodes
)

# I2C Setup for MCP23017
i2c = busio.I2C(board.GP27, board.GP26)
io_expander = MCP23017(i2c)

# Setup for Rotary Encoders via MCP23017
encoder_handler = EncoderHandler()
keyboard.modules.append(encoder_handler)

encoder_handler.pins = [
    ((io_expander.gpb2, io_expander.gpb3), io_expander.gpb0),  # Encoder 1
    ((io_expander.gpb4, io_expander.gpb5), io_expander.gpb1),  # Encoder 2
]

# Define encoder actions
encoder_handler.map = [
    # Encoder 1: Rotate to skip songs, click to mute mic
    [KC_MEDIA_NEXT_TRACK, KC_MEDIA_PREV_TRACK, KC_AUDIO_MUTE],
    # Encoder 2: Rotate to control volume, click to mute audio
    [KC_AUDIO_VOL_UP, KC_AUDIO_VOL_DOWN, KC_MEDIA_PLAY_PAUSE],
]

# RGB LED Setup (SK6812 on GPIO0)
pixels = neopixel.NeoPixel(board.GP0, 8, brightness=0.5, auto_write=False)

def wave_effect():
    t = time.monotonic()
    for i in range(8):
        hue = (math.sin(t + i * 0.5) + 1) / 2  # Generate a wave effect
        pixels[i] = (int(255 * hue), int(255 * (1 - hue)), 128)
    pixels.show()

# Basic Keymap
keyboard.keymap = [
    ["KC_ESC", "KC_1", "KC_2", "KC_3", "KC_4", "KC_5", "KC_6", "KC_7", "KC_8", "KC_9", "KC_0", "KC_MINUS", "KC_EQUAL", "KC_BSPACE", "KC_HOME", "KC_PGUP",
     "KC_TAB", "KC_Q", "KC_W", "KC_E", "KC_R", "KC_T", "KC_Y", "KC_U", "KC_I", "KC_O", "KC_P", "KC_LBRACKET", "KC_RBRACKET", "KC_BSLASH", "KC_END", "KC_PGDOWN",
     "KC_CAPS", "KC_A", "KC_S", "KC_D", "KC_F", "KC_G", "KC_H", "KC_J", "KC_K", "KC_L", "KC_SCOLON", "KC_QUOTE", "KC_ENTER", "KC_UP", "KC_DEL", "KC_INSERT",
     "KC_LSHIFT", "KC_Z", "KC_X", "KC_C", "KC_V", "KC_B", "KC_N", "KC_M", "KC_COMMA", "KC_DOT", "KC_SLASH", "KC_RSHIFT", "KC_LEFT", "KC_DOWN", "KC_RIGHT", "KC_FN",
     "KC_LCTRL", "KC_LGUI", "KC_LALT", "KC_SPACE", "KC_RALT", "KC_RCTRL"]
]

if __name__ == '__main__':
    while True:
        wave_effect()
        keyboard.go()
